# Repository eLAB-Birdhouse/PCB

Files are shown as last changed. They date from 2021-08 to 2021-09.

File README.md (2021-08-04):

This repository contains the design file of the POE hat required for this project.

The design is highly inspired from the following product: https://www.waveshare.com/wiki/ETH/USB_HUB_HAT

A template for the has been used for the hat (it is under a MIT license): https://github.com/rkprojects/kicad-rpiz-uhat-template

Another useful ressource for hat in general is : https://github.com/raspberrypi/hats/blob/master/designguide.md

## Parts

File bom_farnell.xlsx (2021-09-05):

> C3, C7 | 10 nF - 100 V | Capacitor_SMD:C_0402_1005Metric | ~ | 2 | 0
C5 | 1000 pF | Capacitor_SMD:C_0402_1005Metric | ~ | 1 | 0
C12 | 10 nF | Capacitor_SMD:C_0402_1005Metric | ~ | 1 | 0
> C20, C24, C27 | 4.7 µF | Capacitor_SMD:C_0402_1005Metric | ~ | 3 | 20
> C9, C10, C14, C15, C19, C21, C22, C26, C28-C30, C33 | 0.1 µF | Capacitor_SMD:C_0402_1005Metric | ~ | 12 | 0
C31 | 1 µF | Capacitor_SMD:C_0402_1005Metric | ~ | 1 | 0
> C35, C36 | 14 pF | Capacitor_SMD:C_0402_1005Metric | ~ | 2 | 0 | à calculer
> D1, D2 | ABS10 | Diode_SMD:Diode_Bridge_Diotec_ABS | https://be.farnell.com/fr-BE/diodes-inc/abs10b-13/pont-redresseur-1kv-1-5a-sopa/dp/3518278?st=abs10 | 2 | 24
D4 | POE_PWR | LED_SMD:LED_0603_1608Metric | ~ | 1 | 0
D5 | B560C | Diode_SMD:D_SMC | ~ | 1 | 0
D6 | PWR | LED_SMD:LED_0603_1608Metric | ~ | 1 | 0
D7 | OP293B | Package_TO_SOT_THT:TO-46-2 | ~ | 1 | 0
D8 | MBR0520LT1G | Diode_SMD:D_SOD-123 | ~ | 1 | 0
> H1-H4 | MountingHole | lib:MountingHole_2.7mm_M2.5_uHAT_RPi | ~ | 4 | NA
J1 | GPIO_CONNECTOR | lib:PinSocket_2x20_P2.54mm_Vertical_Centered_Anchor | ~ | 1 | 12
J2 | RJHSE-5385 | Connector_RJ:RJ45_Amphenol_RJHSE538X | https://pdf1.alldatasheet.fr/datasheet-pdf/view/541875/AMPHENOL/RJHSE538X.html | 1 | 13
J3 | PIR Motion Sensor | Connector_PinHeader_2.54mm:PinHeader_1x04_P2.54mm_Vertical | ~ | 1 | 18
J4 | DH22T | Connector_PinHeader_2.54mm:PinHeader_1x04_P2.54mm_Vertical | ~ | 1 | 18
J8 | USB_B_Micro | Connector_USB:USB_Micro-B_Molex-105017-0001 | ~ | 1 | 12
JP1 | Jumper_NO_Small | Jumper:SolderJumper-2_P1.3mm_Open_RoundedPad1.0x1.5mm | ~ | 1 | NA
MOD1 | LM2596HVS | user-footprints:Module_LM2596HVS |  | 1 | 2
Q1 | DMG1012UW-7 | Package_TO_SOT_SMD:SOT-323_SC-70 | https://www.diodes.com/assets/Datasheets/ds31783.pdf | 1 | 12
> R1, R2 | 680 | Resistor_SMD:R_0402_1005Metric | ~ | 2 | 80
> R6, R8 | 75 | Resistor_SMD:R_0402_1005Metric | ~ | 2 | 61
> R9, R13 | 2.7k | Resistor_SMD:R_0402_1005Metric | ~ | 2 | 43
R15 | 1k | Resistor_SMD:R_0402_1005Metric | ~ | 1 | 44
R16 | 2.49k 1% | Resistor_SMD:R_0402_1005Metric | ~ | 1 | 44
> R12, R14, R17-R20 | 12k | Resistor_SMD:R_0402_1005Metric | ~ | 6 | 80
TR1 | PT61017PEL | Transformer_SMD:Transformer_Ethernet_Bourns_PT61017PEL | https://www.bourns.com/docs/Product-Datasheets/PT61017PEL.pdf | 1 | 12
U2 | RTL8152B-VB | Package_DFN_QFN:QFN-24-1EP_4x4mm_P0.5mm_EP2.6x2.6mm | https://datasheet.lcsc.com/szlcsc/Realtek-Semicon-RTL8152B-VB-CG_C50656.pdf | 1 | 15
Y2 | 25 MHz 30ppm (HELE(Harmony Elec) X3S025000FC1H-HV) | Crystal:Crystal_SMD_3225-4Pin_3.2x2.5mm | https://be.farnell.com/fr-BE/multicomp/mcsjk-7u-25-00-12-30-60-b-30/quartz-25mhz-12pf-3-2mm-x-2-5mm/dp/2853969 | 1 | 0

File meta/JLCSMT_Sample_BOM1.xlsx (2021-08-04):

Comment | Designator | Footprint | LCSC Part #（optional）
100uF | C1 | CASE-B_3528 | C16133
100nF | C2, C9, C10 | 0603_C | C14663
10uF | C3-5 | 1206_C | C13585
15KΩ | R5, R6 | 0603_R | C22809

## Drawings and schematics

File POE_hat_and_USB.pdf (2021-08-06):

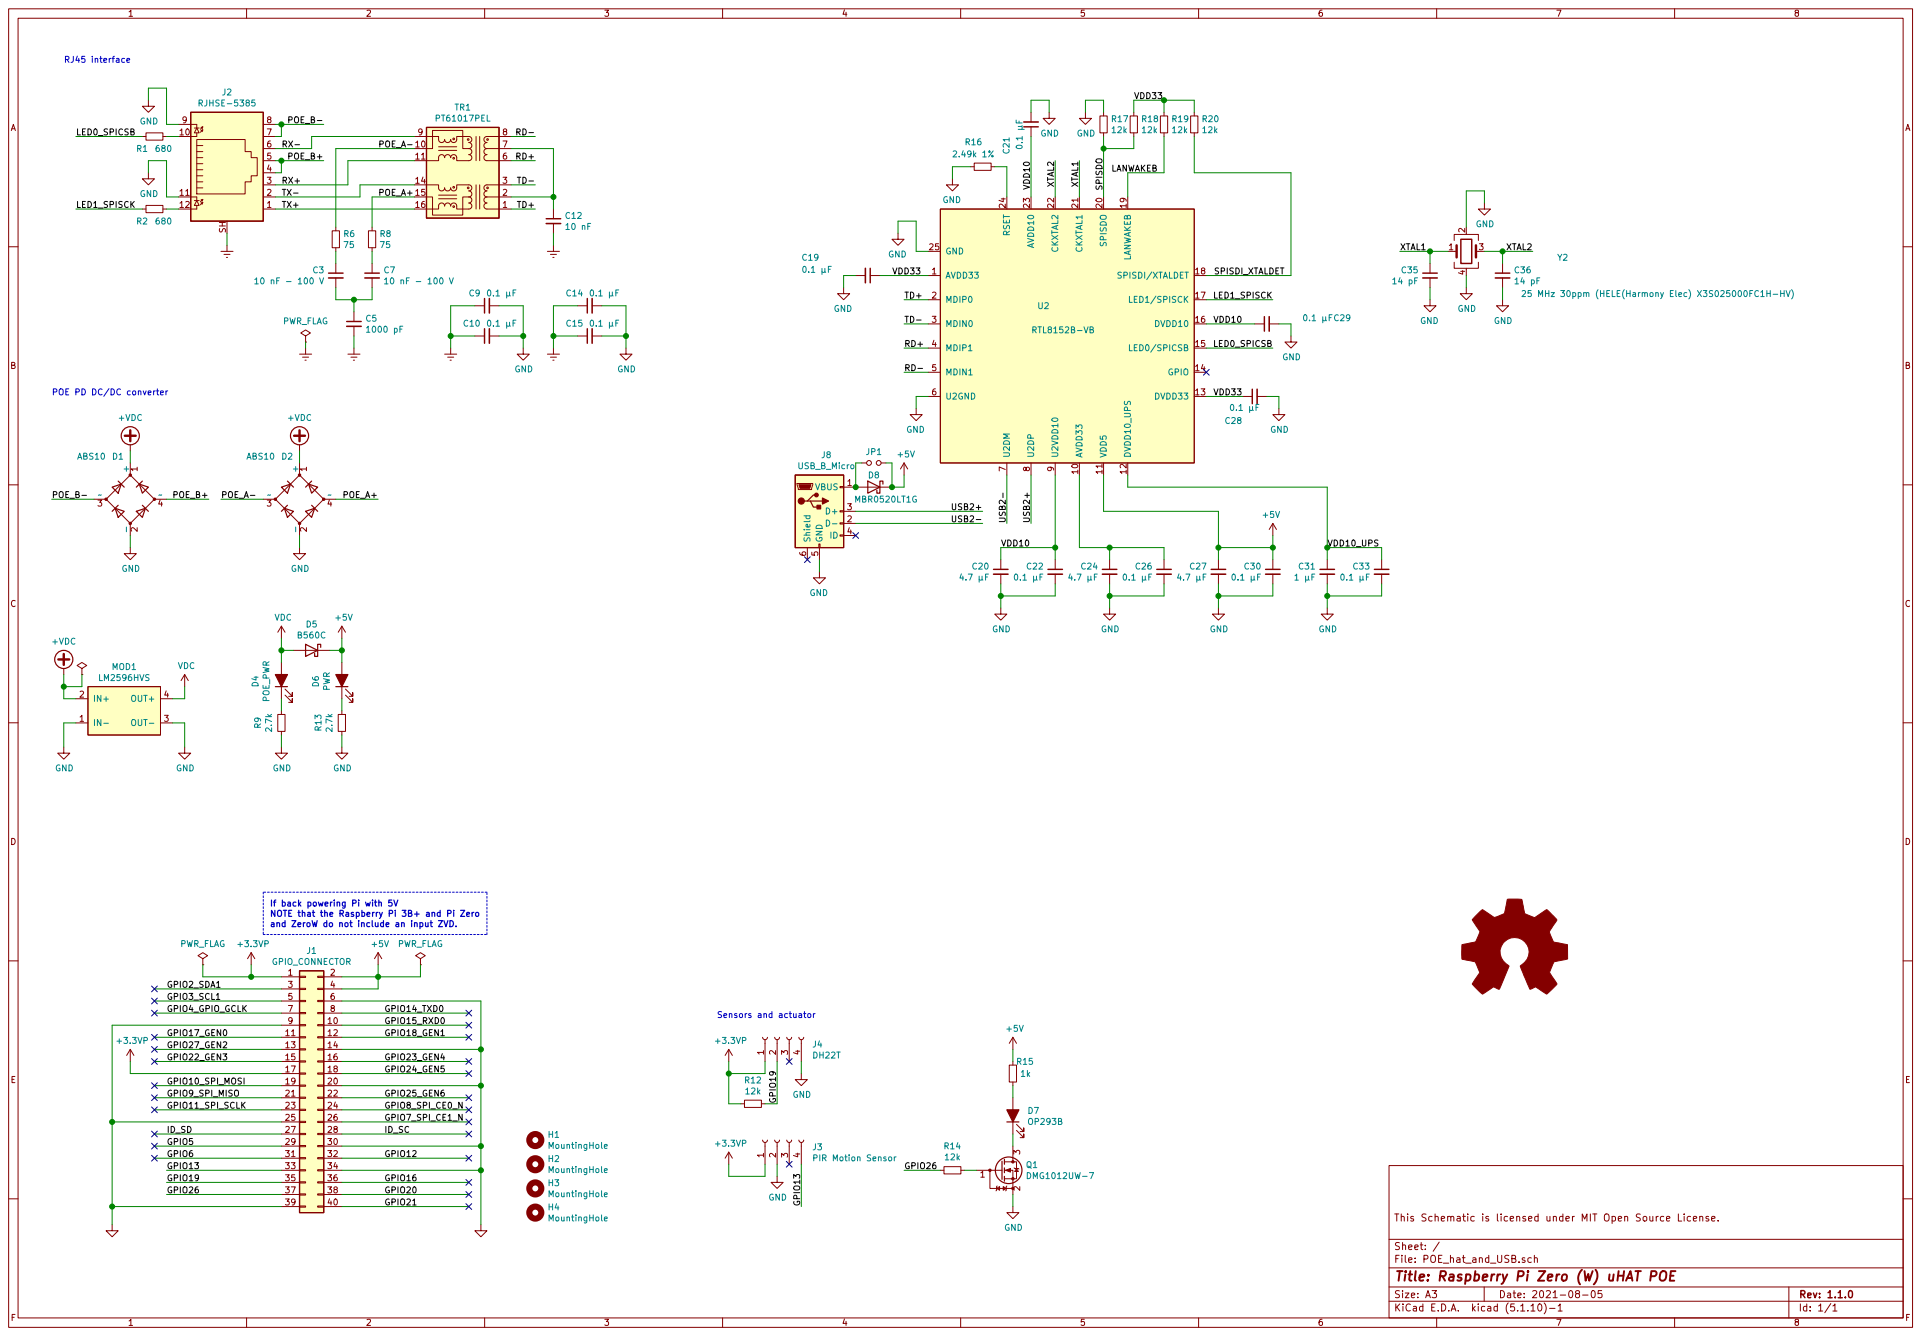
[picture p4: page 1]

POE PD DC/DC converter RJ45 interface

25 MHz 30ppm (HELE(Harmony Elec) X3S025000FC1H-HV) GND GND

If back powering Pi with 5V
NOTE that the Raspberry Pi 3B+ and Pi Zero

File: POE_hat_and_USB.sch Sheet: / This Schematic is licensed under MIT Open Source License.

Id: 1/1 Title: Raspberry Pi Zero (W) uHAT POE

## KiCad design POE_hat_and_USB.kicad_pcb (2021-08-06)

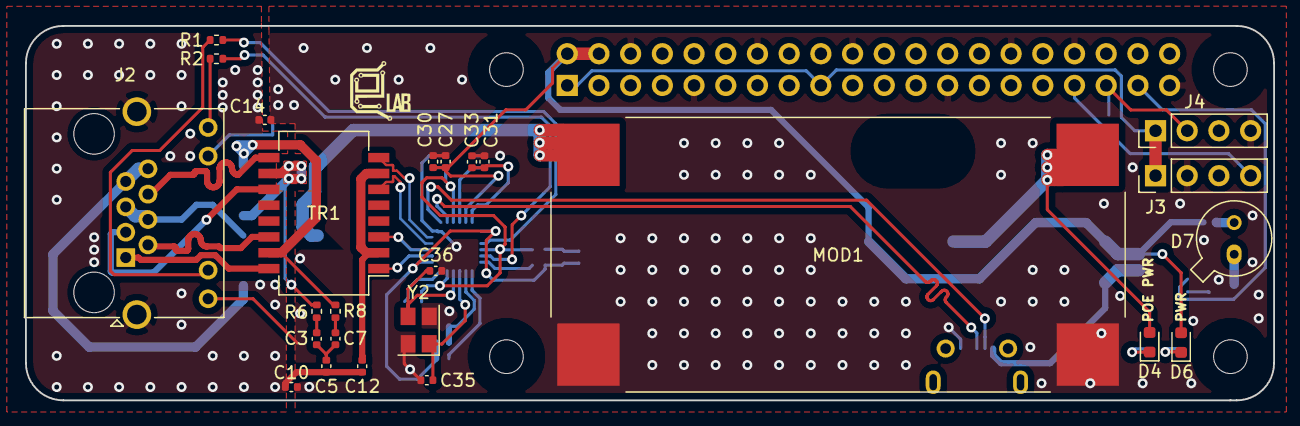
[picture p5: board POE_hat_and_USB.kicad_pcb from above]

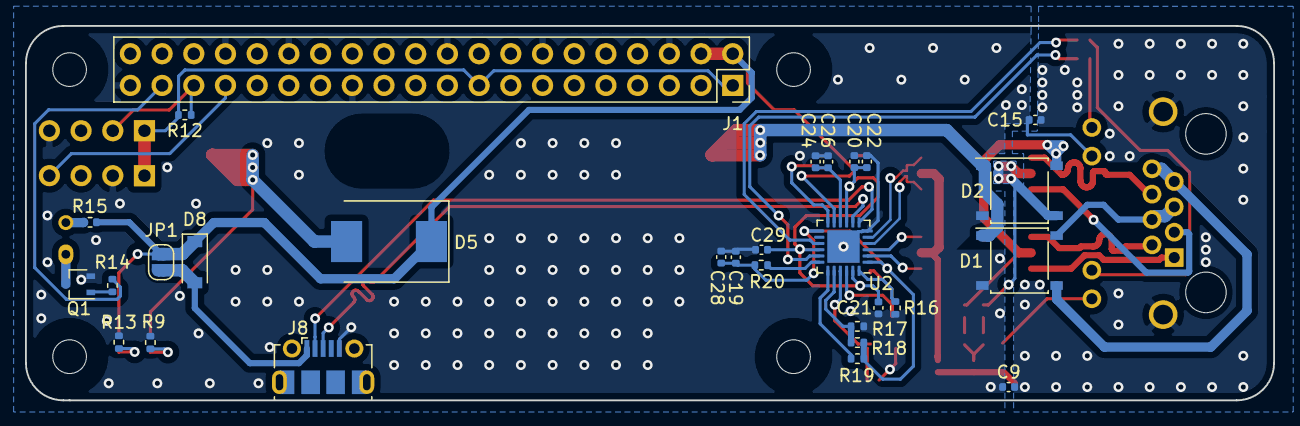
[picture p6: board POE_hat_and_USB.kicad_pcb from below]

Board: 2 copper layers, 100.0 x 30.0 mm, 58 parts (29 on the bottom side), 47 nets.

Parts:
C3, C7: 10 nF - 100 V; C_0402_1005Metric
C5: 1000; C_0402_1005Metric
C9, C10, C14, C15, C19, C21, C22, C26, C28, C29, C30, C33: 0.1; C_0402_1005Metric
C12: 10; C_0402_1005Metric
C20, C24, C27: 4.7; C_0402_1005Metric
C31: 1; C_0402_1005Metric
C35, C36: 14; C_0402_1005Metric
D1, D2: ABS10; Diode_Bridge_Diotec_ABS
D4: POE_PWR; LED_0603_1608Metric
D5: B560C; D_SMC
D6: PWR; LED_0603_1608Metric
D7: OP293B; TO-46-2
D8: MBR0520LT1G; D_SOD-123
H1, H2, H3, H4: MountingHole; MountingHole_2.7mm_M2.5_uHAT_RPi
J1: GPIO_CONNECTOR; PinSocket_2x20_P2.54mm_Vertical_Centered_Anchor
J2: RJHSE-5385; RJ45_Amphenol_RJHSE538X
J3: PIR Motion Sensor; PinHeader_1x04_P2.54mm_Vertical
J4: DH22T; PinHeader_1x04_P2.54mm_Vertical
J8: USB_B_Micro; USB_Micro-B_Molex-105017-0001
JP1: Jumper_NO_Small; SolderJumper-2_P1.3mm_Open_RoundedPad1.0x1.5mm
MOD1: LM2596HVS; Module_LM2596HVS
Q1: DMG1012UW-7; SOT-323_SC-70
R1, R2: 680; R_0402_1005Metric
R6, R8: 75; R_0402_1005Metric
R9, R13: 2.7k; R_0402_1005Metric
R12, R14, R17, R18, R19, R20: 12k; R_0402_1005Metric
R15: 1k; R_0402_1005Metric
R16: 2.49k 1%; R_0402_1005Metric
TR1: PT61017PEL; Transformer_Ethernet_Bourns_PT61017PEL
U2: RTL8152B-VB; QFN-24-1EP_4x4mm_P0.5mm_EP2.6x2.6mm
Y2: 25 MHz 30ppm (HELE(Harmony Elec) X3S025000FC1H-HV); Crystal_SMD_3225-4Pin_3.2x2.5mm

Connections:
+3.3VP: J1.1, J1.17, J3.1, J4.1, R12.2
+5V: C27.1, C30.1, D5.1, D6.2, D8.1, J1.2, J1.4, JP1.1, R15.1, U2.11
+VDC: D1.1, D2.1, MOD1.2
/GPIO13: J1.33, J3.4
/GPIO19: J1.35, J4.2, R12.1
/GPIO26: J1.37, R14.1
/LANWAKEB: R19.2, U2.19
/LED0_SPICSB: R1.1, U2.15
/LED1_SPISCK: R2.1, U2.17
/POE_A+: D2.4, R8.1, TR1.15
/POE_A-: D2.3, R6.1, TR1.10
/POE_B+: D1.4, J2.4, J2.5
/POE_B-: D1.3, J2.7, J2.8
/RD+: TR1.6, U2.4
/RD-: TR1.8, U2.5
/RX+: J2.3, TR1.11
/RX-: J2.6, TR1.9
/SPISDI_XTALDET: R20.2, U2.18
/SPISDO: R17.2, R18.2, U2.20
/TD+: TR1.1, U2.2
/TD-: TR1.3, U2.3
/TX+: J2.1, TR1.16
/TX-: J2.2, TR1.14
/USB2+: J8.3, U2.8
/USB2-: J8.2, U2.7
/VDD10: C20.1, C21.1, C22.1, C29.1, U2.9, U2.16, U2.23
/VDD10_UPS: C31.1, C33.1, U2.12
/VDD33: C19.1, C28.1, R18.1, R19.1, R20.1, U2.1, U2.13
/XTAL1: C35.1, U2.21, Y2.1
/XTAL2: C36.1, U2.22, Y2.3
Earth: C5.2, C9.1, C10.1, C12.2, C14.1, C15.1, J2.SH
GND: C9.2, C10.2, C14.2, C15.2, C19.2, C20.2, C21.2, C22.2, C24.2, C26.2, C27.2, C28.2, C29.2, C30.2, C31.2, C33.2, C35.2, C36.2, D1.2, D2.2, J1.6, J1.9, J1.14, J1.20, J1.25, J1.30, J1.34, J1.39, J2.9, J2.11, J3.2, J4.4, J8.5, MOD1.1, MOD1.3, Q1.2, R9.2, R13.2, R16.1, R17.1, U2.6, U2.25, Y2.2, Y2.4
unnamed: C3.1, R6.2
unnamed: C3.2, C5.1, C7.2
unnamed: C7.1, R8.2
unnamed: C12.1, TR1.2, TR1.7
unnamed: C24.1, C26.1, U2.10
unnamed: D4.1, R9.1
unnamed: D6.1, R13.1
unnamed: D7.1, Q1.3
unnamed: D7.2, R15.2
unnamed: D8.2, J8.1, JP1.2
unnamed: J2.10, R1.2
unnamed: J2.12, R2.2
unnamed: Q1.1, R14.2
unnamed: R16.2, U2.24
VDC: D4.2, D5.2, MOD1.4

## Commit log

2021-08-04 Initial version (not viable).
    [JLCSMT_Sample_BOM1.xlsx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]
2021-08-04 Remove power supply and USB hub.
    [POE_hat_and_USB.kicad_pcb, POE_hat_and_USB.sch]
2021-08-05 Create footprint and symbol for the LM2596HVS
2021-08-05 Add LM2596HVS to schematic.
    [POE_hat_and_USB.sch]
2021-08-05 Clean up project.
    [POE_hat_and_USB-B_Cu.gbl, POE_hat_and_USB-B_Mask.gbs, POE_hat_and_USB-B_Paste.gbp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]
2021-08-06 Reroute PCB (removing USB hub, changing power supply and crystal).
    [POE_hat_and_USB.kicad_pcb, POE_hat_and_USB.sch]
2021-08-06 v1.1.0 prerelease.
    [POE_hat_and_USB.kicad_pcb]
2021-09-04 Add prod files (JLCPCB).
    [POE_hat_and_USB-B_Cu.gbl, POE_hat_and_USB-B_Mask.gbs, POE_hat_and_USB-B_Paste.gbp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]

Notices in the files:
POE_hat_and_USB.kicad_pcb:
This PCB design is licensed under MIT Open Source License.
